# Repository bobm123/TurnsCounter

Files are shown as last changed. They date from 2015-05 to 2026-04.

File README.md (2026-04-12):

# Rubber Band Winder Turns Counter

A turns counter for 3D-printed model airplane rubber band winders. Uses two hall effect sensors to count shaft rotations with direction detection, displayed on a small COG LCD.

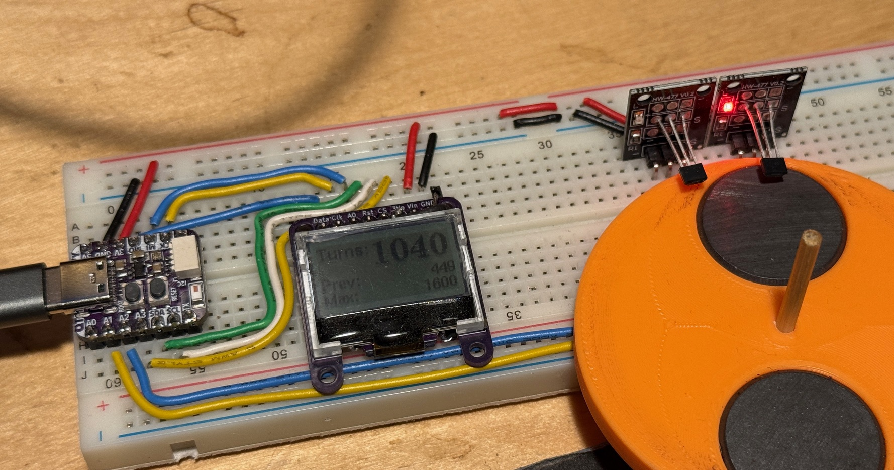
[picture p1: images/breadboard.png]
Breadboard prototype


## Hardware

| Component | Description |
| --- | --- |
| [Adafruit QT Py ESP32-C3](https://www.adafruit.com/product/5405) | Microcontroller board |
| [ERC12864FSF-11](https://www.buydisplay.com/0-96-inch-low-cost-white-128x64-graphic-cog-lcd-display-st7567-spi) | 128x64 COG LCD (ST7567 controller) on [custom breakout board](../../../COGDisplayBreakout/COGDisplayBreakout/) |
| APX805S | Power-on reset IC for display /RST line (on breakout board) |
| 2x KY-003 | Hall effect sensor modules (left and right) |
| Magnet | Mounted on the winder output shaft |

### Pin Mapping

| Function | QT Py Pin | ESP32-C3 GPIO |
| --- | --- | --- |
| Hall sensor - left  | A0 | 4 |
| Hall sensor - right | A1 | 3 |
| Button (BOOT) | BOOT | 9 |
| NeoPixel | - | 2 |
| Display SCK | SCK | 10 |
| Display SDA | MO | 7 |
| Display CS | - | tied low |
| Display DC | MI | 8 |
| Display RST | - | APX805S |
| Backlight LED | A3 | 0 |

## Features

### Turn Counting

Two KY-003 hall effect sensors detect a magnet on the rotating shaft. The left sensor triggers an interrupt; at that moment the right sensor is read to determine direction:

- Left sensor activates first: count increments (winding)
- Right sensor activates first: count decrements (unwinding)

### Display

The 128x64 LCD shows three values:

- **Turns** - current count (large font)
- **Prev** - count saved from last reset
- **Max** - maximum turns set point

### Button (BOOT)

- **Short press** (normal mode): saves current count to "Prev" and resets count to zero
- **Short press** (set-mode): exits set-mode
- **Long press** (3 seconds): enters set-mode, where turning the crank adjusts the max turns value by +/-10 per turn. The max value flashes on the display while in set-mode.

### Warnings

As the absolute turn count approaches the max set point:

- **80%**: NeoPixel flashes yellow
- **90%**: NeoPixel flashes red, backlight flashes

Warnings trigger regardless of winding direction since rubber bands break under strain in either direction.

### Backlight Sleep

The backlight turns off after 1 minute of inactivity (no turns or button presses) and turns back on automatically when activity resumes. The LCD remains readable without the backlight in good lighting.

## Building

### Dependencies

Install these via the Arduino IDE Library Manager:

- [U8g2](https://github.com/olikraus/u8g2) - display graphics
- [Adafruit NeoPixel](https://github.com/adafruit/Adafruit_NeoPixel) - RGB LED control

### Board Setup

1. In Arduino IDE, install the ESP32 board support package
2. Select board: **Adafruit QT Py ESP32-C3**
3. Open `ERC12864_TurnsCounter/ERC12864_TurnsCounter.ino`
4. Compile and upload

### Troubleshooting

- **Direction inverted**: swap `HALL_LEFT` and `HALL_RIGHT` pin definitions
- **Double-counting**: increase `DEBOUNCE_MS` (default 10)
- **Missing counts at speed**: decrease `DEBOUNCE_MS`
- Serial monitor at 115200 baud prints turn counts and button events

## Repository Structure

```
ERC12864_TurnsCounter/   Current sketch (QT Py ESP32-C3 + ERC12864 LCD)
TurnsCounter/            Original reference sketch (ATmega + SSD1306 OLED)
JulianCode/              Reference: low-level SSD1306 OLED control
PinChangeInterrupts/     Reference: AVR pin-change interrupts
U8libExample/            Reference: U8glib display example
SoftServoExample/        Reference: Adafruit Trinket servo control
blinknodelay/            Reference: non-blocking blink pattern
Documents/               Datasheets (QT Py, hall effect sensors, displays)
STLs/                    3D printed parts (magnet disk for shaft)
```

## Future Plans

- LiPo battery support via [Adafruit LiPo Charger BFF](https://www.adafruit.com/product/5397) (A2 is now free for battery voltage sensing)
- Deep sleep mode with NVS save/restore of turn count
- Progress bar on display
- Custom PC board to replace the breadboard wiring
- Battery charge indicator

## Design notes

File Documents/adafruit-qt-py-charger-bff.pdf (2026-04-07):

# Adafruit LiIon or LiPoly Charger BFF Add-On for QT Py

Created by Kattni Rembor

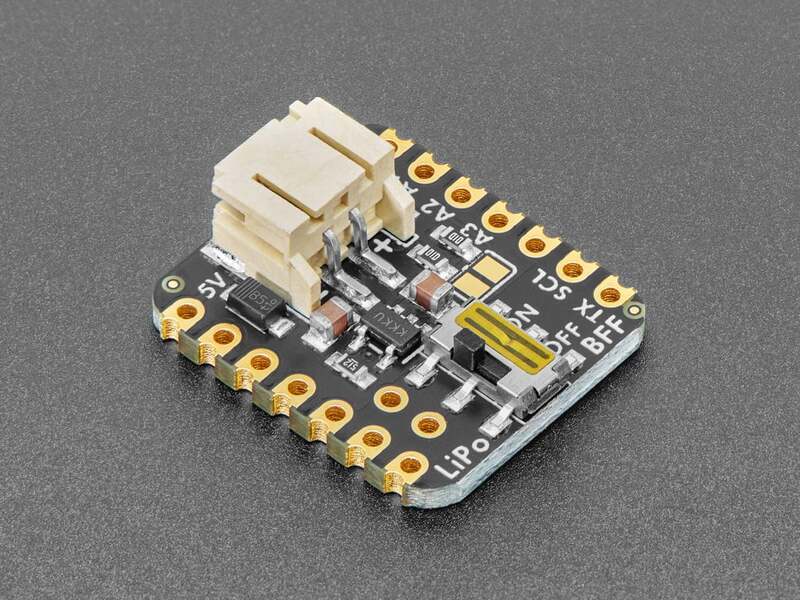
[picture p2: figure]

https://learn.adafruit.com/adafruit-qt-py-charger-bff

Last updated on 2025-12-19 03:03:49 PM UTC

©Adafruit Industries | Page 1 of 14

3
7

11

## Table of Contents

Overview
Pinouts
- Power Slide Switch
- Power Switch Breakout Pads
- Battery JST Connector
- Charge LED
- Battery Monitor Pin and Jumper
- Charge Chip and Voltage Divider
Downloads
- Files
- Schematic and Fab Print
- 3D Model

# Overview

Is your QT Py all alone (https://www.adafruit.com/?q=qt+py&sort=BestMatch) (https://adafru.it/18eZ), lacking a friend to travel the wide world with? When you were a kid you may have learned about the "buddy" system. Well, this product is kinda like that! A board that will watch your QT Py's back and give it the power and support to wander out past your USB port.

Revision History:
As of December 12, 2025 - We added two breakout pads for the on/off switch for an external switch if desired. We also updated the PCB with Adafruit Pinguin to make a lovely and legible silkscreen.

•

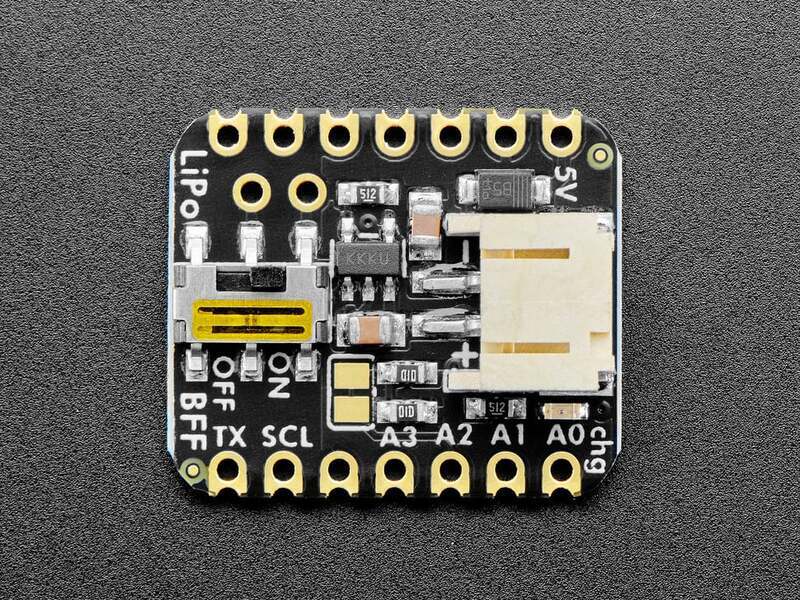
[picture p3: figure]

This little lipo charger is designed to fit onto the back of any QT Py board, and make it easy for portable powering. Simply plug any standard 3.7V/4.2V lithium polymer or lithium-ion rechargeable battery into the JST plug on the end. When powered by the USB port on the QT Py, the charger kicks in and will charge up the battery at 200mA max rate. You'll see the yellow LED light up when that happens.
When the USB is removed, the battery will reverse charge into the 5V port via a Schottky diode. You can turn it on or off with the built in slide switch as well.

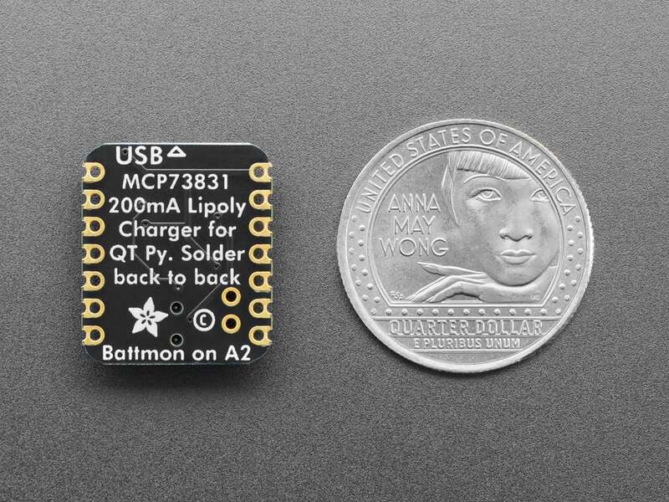
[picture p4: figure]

A simple voltage divider on the cathode side of the diode and connected to pin A2 will let your firmware detect basic modes: if the voltage is over 4.3V, it is probably plugged into USB. If the voltage is 4.2V or below its probably running on the Lipoly battery and you can roughly determine the battery state.

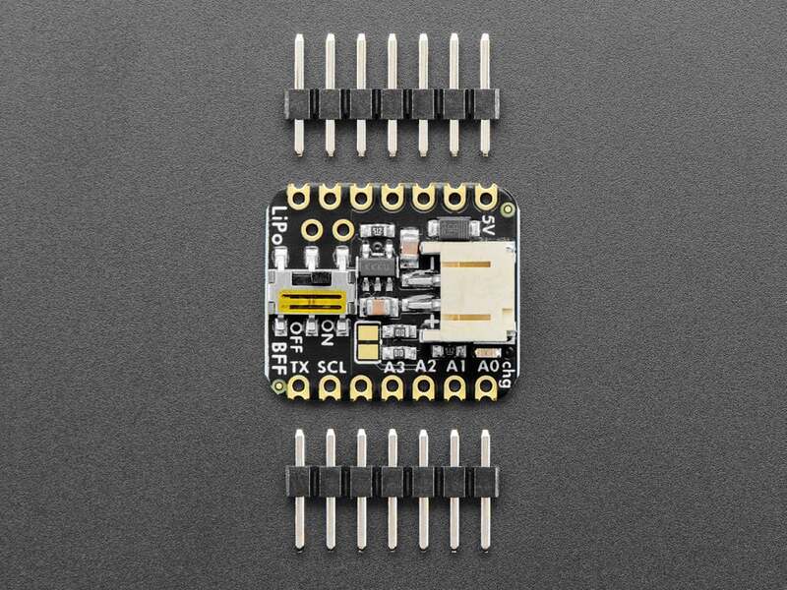
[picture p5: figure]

We include some header that you can solder to your QT Py. You can also pick up an Itsy Bitsy short female header kit to make it removable but compact (https://www.adafruit.com/product/4174) (http://adafru.it/4174), you'll just need to trim down the headers to 7 pins long.
For use with Adafruit LiPoly/LiIon batteries only! Other batteries may have different voltage, chemistry, polarity, or pinout.

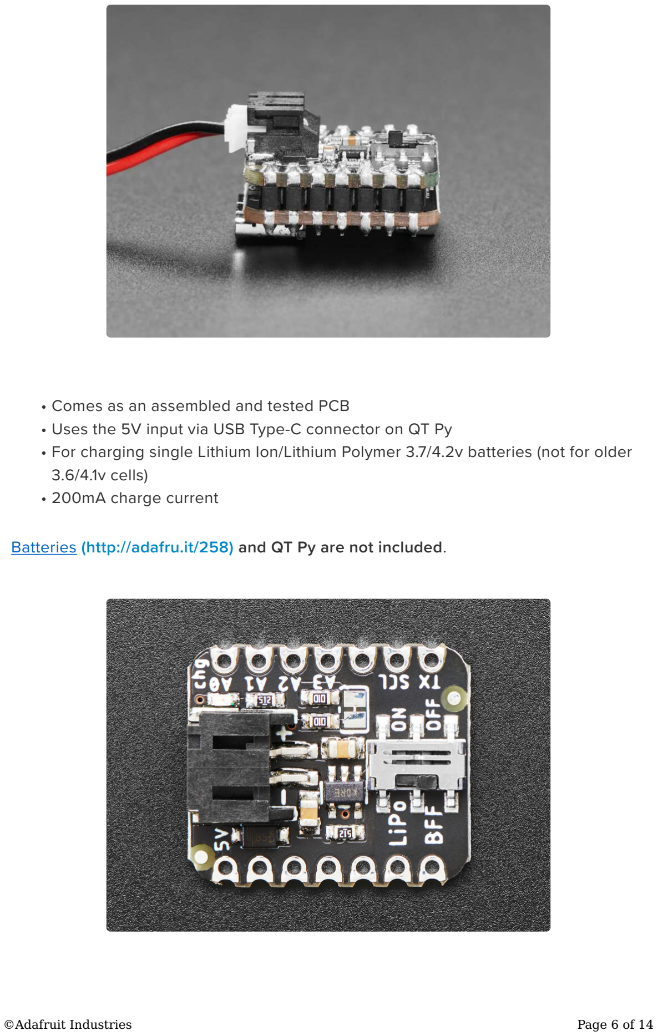
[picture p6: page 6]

Comes as an assembled and tested PCB
Uses the 5V input via USB Type-C connector on QT Py
For charging single Lithium Ion/Lithium Polymer 3.7/4.2v batteries (not for older 3.6/4.1v cells)
200mA charge current

Batteries (http://www.adafruit.com/products/258) (http://adafru.it/258) and QT Py are not included.

•
•
•

•

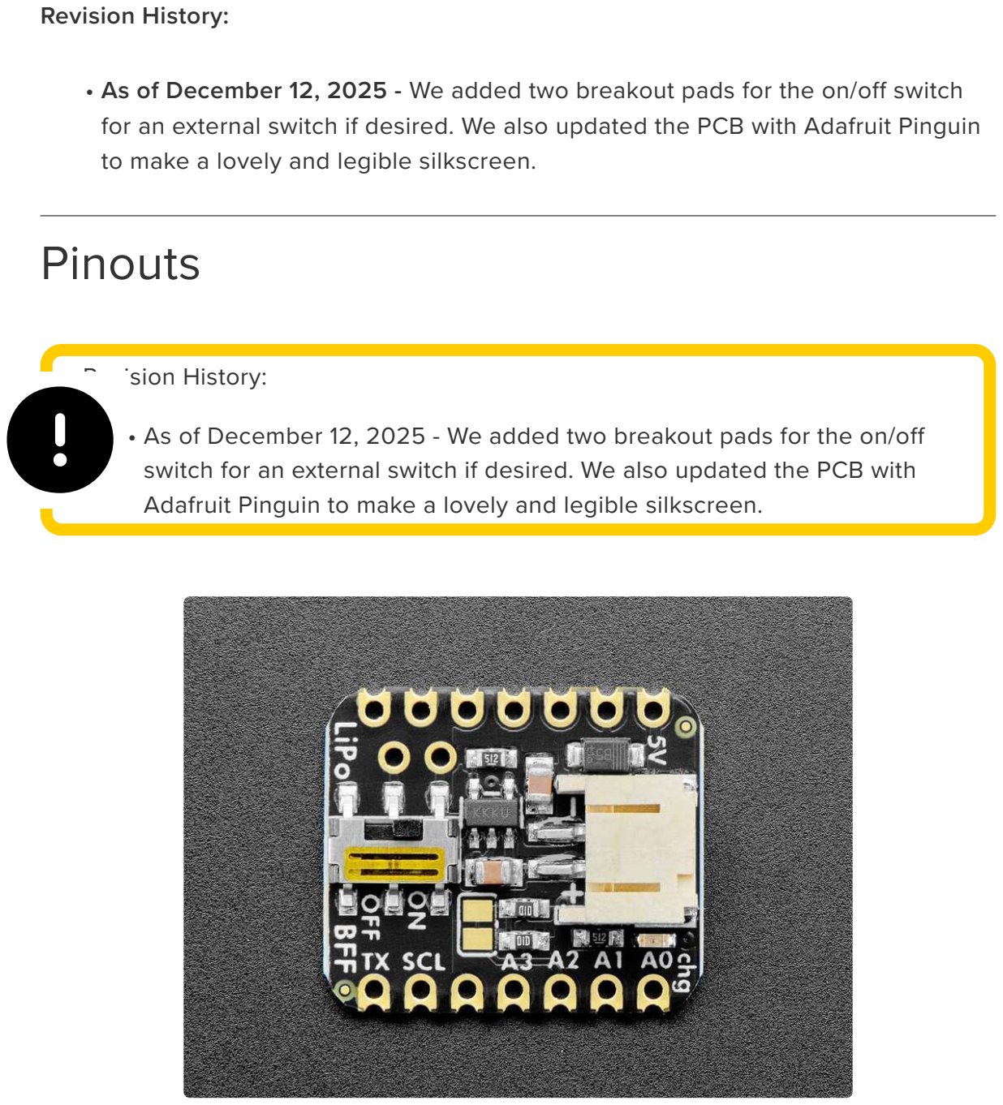
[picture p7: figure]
Revision History:; Pinouts

As of December 12, 2025 - We added two breakout pads for the on/off switch for an external switch if desired. We also updated the PCB with Adafruit Pinguin to make a lovely and legible silkscreen.

As of December 12, 2025 - We added two breakout pads for the on/off switch for an external switch if desired. We also updated the PCB with Adafruit Pinguin to make a lovely and legible silkscreen.

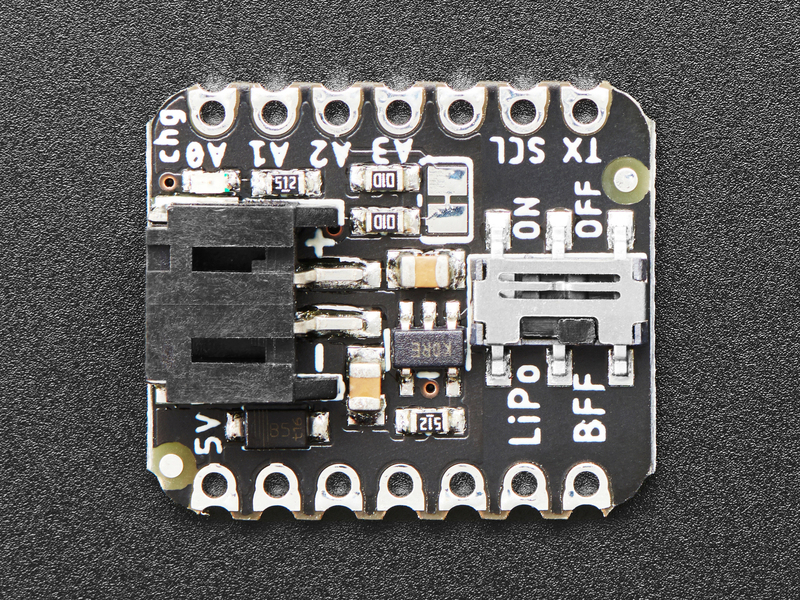
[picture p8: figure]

This QT Py BFF has a bunch of features packed into a cute little board. This page will explain the hardware!

## Power Slide Switch

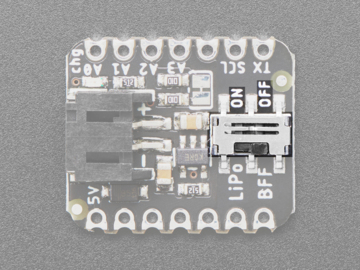
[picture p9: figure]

The power slide switch, located in the middle of the right side of the board, turns the BFF on or off, but only when the QT Py is NOT plugged into USB power.

## Power Switch Breakout Pads

On rev C of the BFF are power switch breakout pads. They are located next to the power slide switch and let you wire up an external switch to use instead of the slide switch.

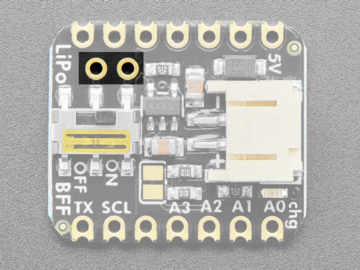
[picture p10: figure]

## Battery JST Connector

The battery JST connector, located in the middle of the left side of the board, enables you to plug in any standard 3.7V/ 4.2V lithium polymer or lithium-ion rechargeable battery to the BFF.
For use with Adafruit LiPoly/LiIon batteries only! Other batteries may have different voltage, chemistry, polarity, or pinout.

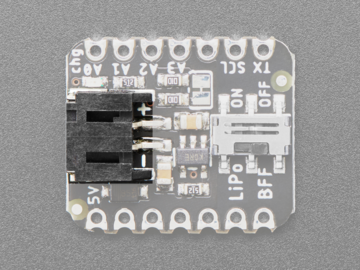
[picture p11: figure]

## Charge LED

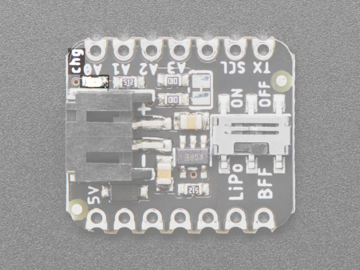
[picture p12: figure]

The charge LED, located in the upper left corner of the board, lights up when the battery is charging. Charging occurs only when the QT Py is plugged into USB power.

## Battery Monitor Pin and Jumper

Pin A2, located to the left of center along the top edge of the board, is connected to the simple voltage divider, which will let your firmware detect basic modes.
It measure the 5V line which is after a schottkey diode.
If the voltage is over 2.0V (4V divided by two due to the divider), it is probably plugged into USB. If the voltage is 1.95V or below, it's probably running on the Lipoly battery and you can roughly determine the battery state.
Just be sure to double the reading to get the voltage reading, as the measurement divider reduces the voltage by 1/2.

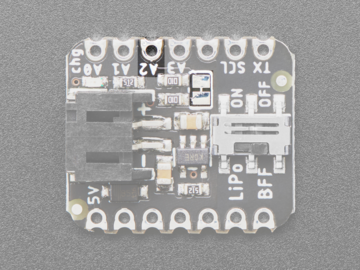
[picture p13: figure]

There are a pair of jumper pads, located to the right of center, below the pins along the top edge. These pads are connected to pin A2, between the pin and the voltage divider. In the event that you want to use pin A2 for something other than battery monitoring, you can cut the trace between these pads to disable monitoring on pin A2. Solder the pads back together to enable monitoring again.

## Charge Chip and Voltage Divider

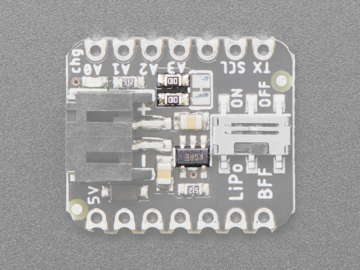
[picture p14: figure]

The MCP73831 lipo charge chip, located near the center of the board, will charge up the battery at 200mA max rate. Charging occurs only while the QT Py is plugged into USB, and will happen regardless of the status of the slide switch. When the chip is charging a battery, the charge LED will light up.

The voltage divider, located below the A3 pin label on the BFF silk, is connected between A2 and 5V via the cathode side of a diode. It allows for simple monitoring of voltage levels, which can indicate whether the QT Py is running off USB, or being powered by a battery plugged into the BFF.
To obtain the voltage level from A2 using CircuitPython, run the following code.

import time
import board
import analogio

analog_pin = analogio.AnalogIn(board.A2)

def get_voltage(pin):
return (pin.value / 65535) * 3.3 * 2.0 // voltage divider reduces // voltage by 1/2 do must
// double to get the voltage while True:
print(get_voltage(analog_pin)) time.sleep(0.1)

# Downloads

## Files

MCP73831 Datasheet (https://cdn-learn.adafruit.com/assets/assets/000/110/654/original/MCP73831-Family-Data-Sheet-DS20001984H.pdf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) (https://adafru.it/Zzd)
EagleCAD PCB files on GitHub (https://github.com/adafruit/Adafruit-Charger-BFF-PCB) (https://adafru.it/Zze)
Fritzing object in the Adafruit Fritzing Library - rev B (https://github.com/adafruit/Fritzing-Library/blob/master/parts/Adafruit%20LiPoly%20Charger%20BFF%20for%20QT%20Py_rev%20A.fzpz) (https://adafru.it/1ayc) Fritzing object in the Adafruit Fritzing Library - rev C (https://github.com/adafruit/Fritzing-Library/blob/master/parts/Adafruit%20LiPoly%20Charger%20BFF%20for%20QT%20Py_rev%20C.fzpz) (https://adafru.it/1ayd) 3D models on GitHub (https://github.com/adafruit/Adafruit_CAD_Parts/tree/main/5397%20Lipo%20Charger%20BFF) (https://adafru.it/18f0)

•
•
•
•
•

## Schematic and Fab Print

Rev C

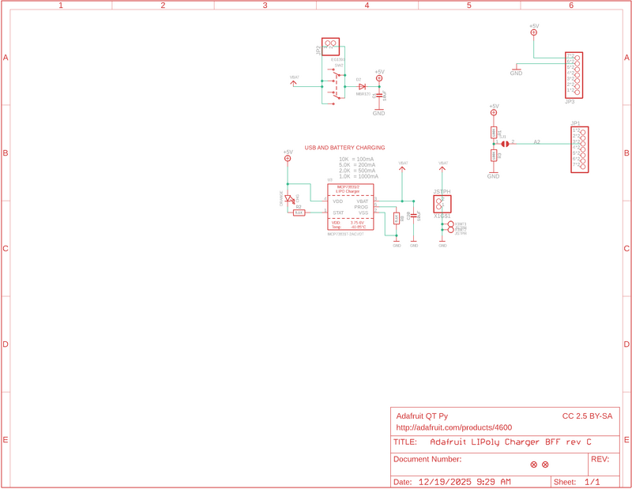
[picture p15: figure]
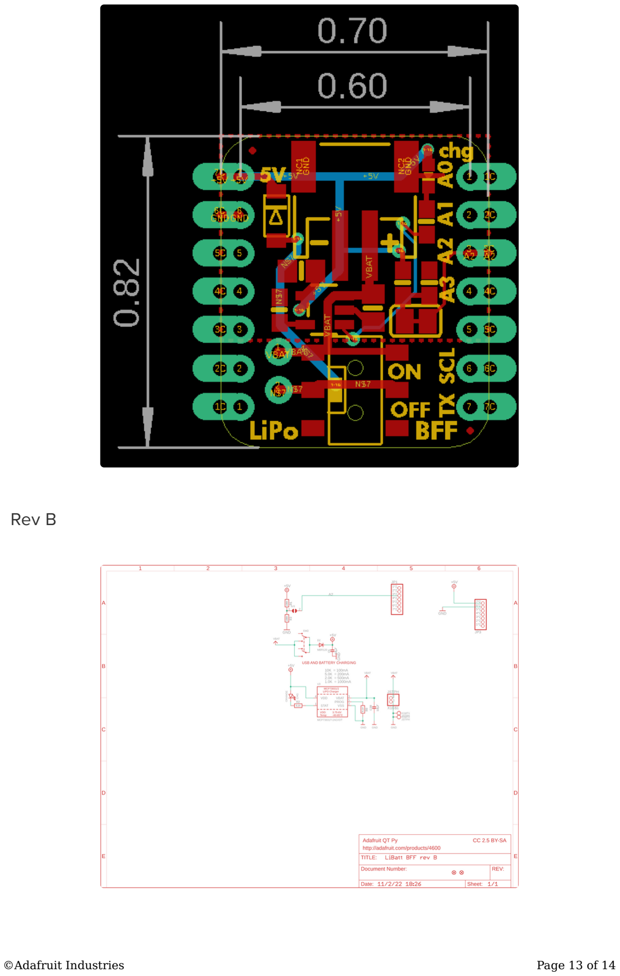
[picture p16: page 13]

Rev B

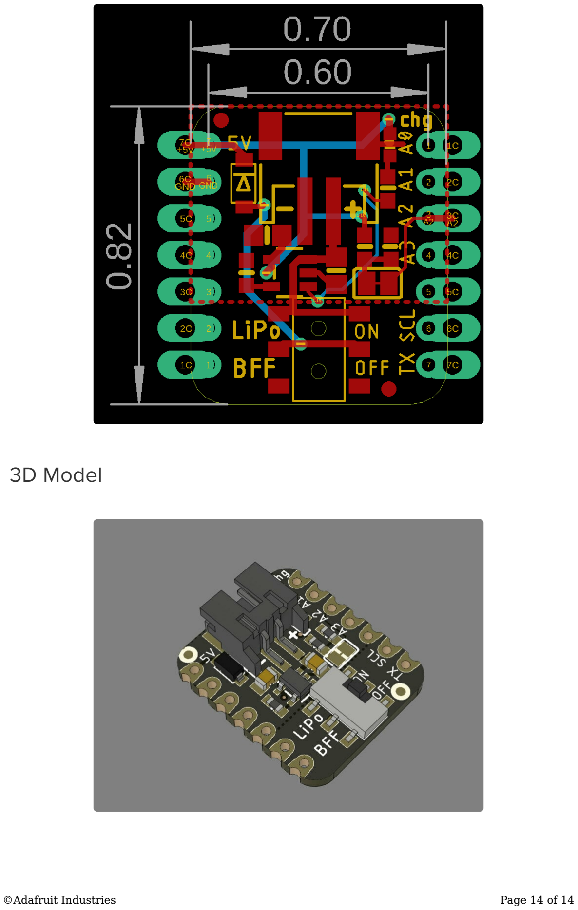
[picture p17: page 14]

## 3D Model

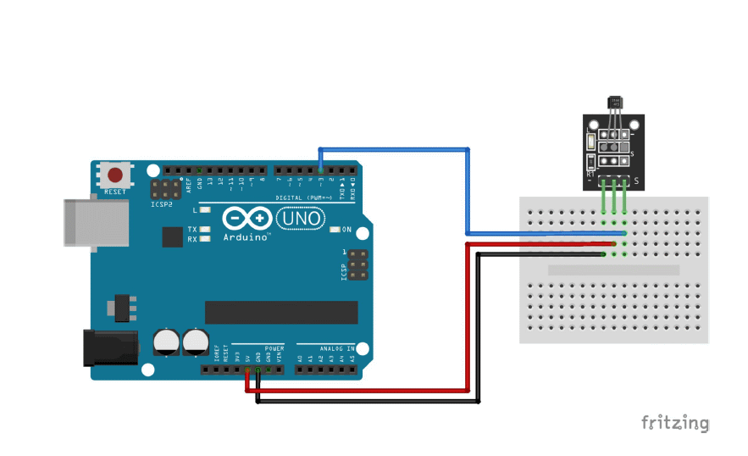
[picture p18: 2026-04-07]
Documents/Uno+HallEffectModule.gif

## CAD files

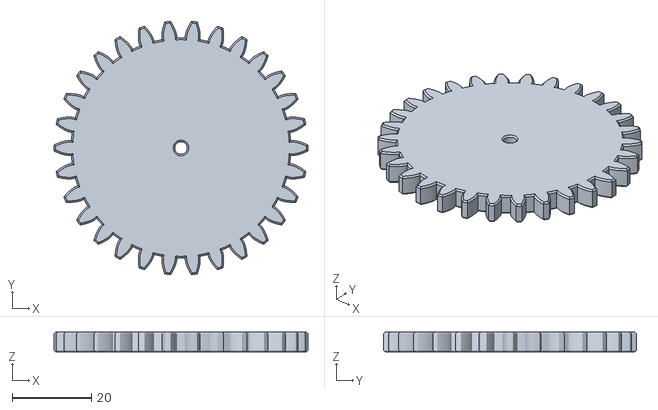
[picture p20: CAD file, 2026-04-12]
STLs/Spur Gear (30 teeth).stl
64.0 x 63.8 x 5.00

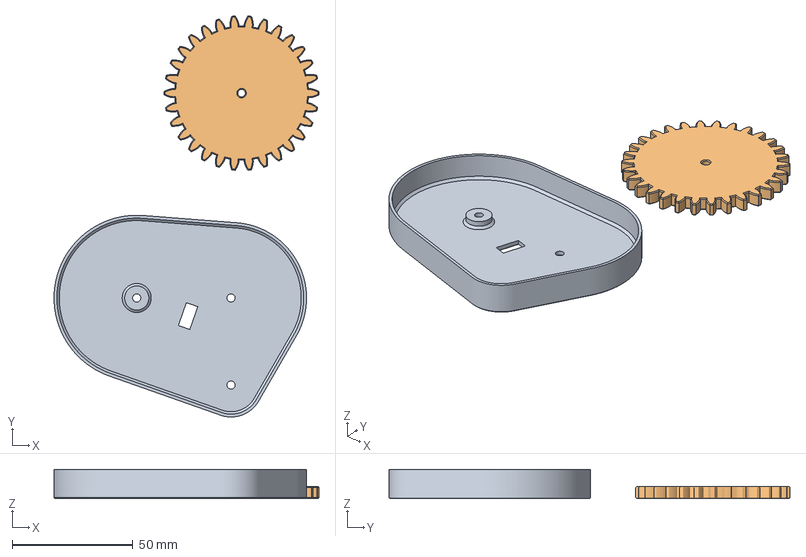
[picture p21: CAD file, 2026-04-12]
STLs/ElectronicsBay.3mf
109.5 x 165.8 x 12.0 mm
ElectronicsBay.stl
Spur Gear (30 teeth).stl

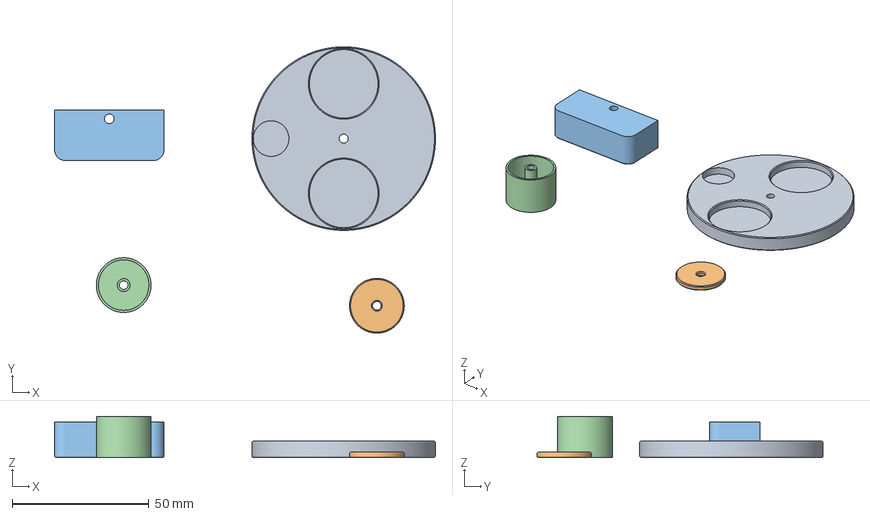
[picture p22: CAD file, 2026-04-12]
STLs/MagnetDisk.3mf
139.1 x 104.5 x 15.0 mm
MagnetDisk.stl
Washer.stl
MagnetDisk-bearing.stl
SeamTest.stl

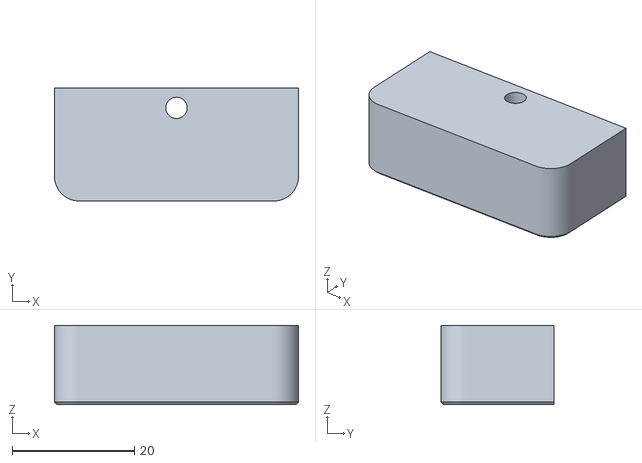
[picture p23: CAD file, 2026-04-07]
STLs/MagnetDisk-bearing.stl
40.0 x 18.5 x 13.0

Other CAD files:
STLs/MagnetDisk.stl

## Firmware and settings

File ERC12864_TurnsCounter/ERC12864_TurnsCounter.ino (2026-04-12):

#include <U8g2lib.h>
#include <SPI.h>
#include <Adafruit_NeoPixel.h>

// QT Py ESP32-C3 display pin mappings
// CS tied low on breakout (single SPI device). RST managed by APX805S on breakout board.
U8G2_ST7565_ERC12864_ALT_F_4W_SW_SPI u8g2(U8G2_R0, /* clock=*/ 10, /* data=*/ 7, /* cs=*/ U8X8_PIN_NONE, /* dc=*/ 8, /* reset=*/ U8X8_PIN_NONE);
#define BACKLIGHT_LED 0

// Hall effect sensor pins (KY-003 modules)
// Left sensor triggers the interrupt; right sensor is read for direction
#define HALL_LEFT   4   // A0 = GPIO4 - interrupt pin
#define HALL_RIGHT  3   // A1 = GPIO3 - direction pin

// Button pin (BOOT button on QT Py ESP32-C3)
#define BUTTON_PIN  9   // GPIO9 - active LOW with internal pull-up

// NeoPixel
#define NEOPIXEL_PIN 2
Adafruit_NeoPixel pixel(1, NEOPIXEL_PIN, NEO_GRB + NEO_KHZ800);

// Warning thresholds (percentage of maxTurns)
#define WARN_THRESHOLD  80
#define ALERT_THRESHOLD 90

// Debounce time in milliseconds
#define DEBOUNCE_MS 10

// Inactivity timeout for backlight (milliseconds)
#define INACTIVE_TIMEOUT 60000

// Long press threshold to enter set-mode (milliseconds)
#define SETMODE_TIME 3000

// Default max turns
#define DEFAULT_MAX 1600

// Volatile state shared between ISR and main loop
volatile int gEncoderPos = 0;
volatile unsigned long gLastInterruptTime = 0;
volatile unsigned long gLastActivityTime = 0;

// ISR: called on FALLING edge of left hall sensor (magnet detected)
void IRAM_ATTR hallSensorISR() {
  unsigned long now = millis();
  if (now - gLastInterruptTime < DEBOUNCE_MS) {
    return;
  }
  gLastInterruptTime = now;

  gLastActivityTime = now;

  // Same state = winding (left closed first), different = unwinding
  if (digitalRead(HALL_LEFT) == digitalRead(HALL_RIGHT)) {
    gEncoderPos++;
  } else {
    gEncoderPos--;
  }
}

void setup() {
  Serial.begin(115200);
  Serial.println("Turns Counter - Hall Effect");

  // Backlight on
  pinMode(BACKLIGHT_LED, OUTPUT);
  digitalWrite(BACKLIGHT_LED, HIGH);

  // NeoPixel power enable and init
#ifdef NEOPIXEL_POWER
  pinMode(NEOPIXEL_POWER, OUTPUT);
  digitalWrite(NEOPIXEL_POWER, HIGH);
#endif
  pixel.begin();
  pixel.setBrightness(50);
  pixel.clear();
  pixel.show();

  // Hall effect sensor inputs
  pinMode(HALL_LEFT, INPUT_PULLUP);
  pinMode(HALL_RIGHT, INPUT_PULLUP);

  // Button input (active LOW, has internal pull-up on the board)
  pinMode(BUTTON_PIN, INPUT_PULLUP);

  // Interrupt on left sensor: FALLING = magnet detected (KY-003 goes LOW)
  attachInterrupt(HALL_LEFT, hallSensorISR, FALLING);

  // Initialize display
  u8g2.begin();
}

int turnsCount = 0;
int prevTurns = 0;       // saved count from last reset
int maxTurns = DEFAULT_MAX;
int prevEncoderPos = 0;
int prevDisplayedCount = -99999;
bool setMode = false;
bool buttonWasUp = true;
unsigned long buttonDownTime = 0;
bool longPressHandled = false;
char buffer[12];

void loop() {
  unsigned long now = millis();

  // --- Encoder delta ---
  int encoderPos = gEncoderPos;
  int delta = encoderPos - prevEncoderPos;
  if (delta != 0) {
    prevEncoderPos = encoderPos;
    if (setMode) {
      maxTurns += 10 * delta;
      if (maxTurns < 0) maxTurns = 0;
    } else {
      turnsCount += delta;
    }
  }

  // --- Button state machine ---
  bool buttonDown = (digitalRead(BUTTON_PIN) == LOW);

  if (buttonDown && buttonWasUp) {
    // Button just pressed
    buttonDownTime = now;
    longPressHandled = false;
    gLastActivityTime = now;
  }

  if (buttonDown && !buttonWasUp) {
    // Button held - check for long press
    if (!longPressHandled && (now - buttonDownTime > SETMODE_TIME)) {
      longPressHandled = true;
      if (!setMode) {
        setMode = true;
        Serial.println("Set mode ON");
      }
    }
  }

  if (!buttonDown && !buttonWasUp) {
    // Button just released
    if (!longPressHandled) {
      // Short press
      if (setMode) {
        setMode = false;
        Serial.print("Set mode OFF, max=");
        Serial.println(maxTurns);
      } else {
        prevTurns = turnsCount;
        turnsCount = 0;
        gEncoderPos = 0;
        prevEncoderPos = 0;
        Serial.print("Reset. Prev=");
        Serial.println(prevTurns);
      }
    }
    gLastActivityTime = now;
  }

  buttonWasUp = !buttonDown;

  // --- Serial debug on count change ---
  if (turnsCount != prevDisplayedCount) {
    prevDisplayedCount = turnsCount;
    Serial.print("Turns: ");
    Serial.println(turnsCount);
  }

  // --- Warning indicators and backlight ---
  int pctMax = (maxTurns > 0) ? (100L * abs(turnsCount) / maxTurns) : 0;
  bool active = (now - gLastActivityTime) < INACTIVE_TIMEOUT;

  if (!active) {
    // Inactive - backlight off, NeoPixel off
    digitalWrite(BACKLIGHT_LED, LOW);
    pixel.clear();
  } else if (pctMax >= ALERT_THRESHOLD) {
    // Over 90%: fast flash red NeoPixel + backlight
    bool flash = (now / 100) % 2;  // ~5 Hz
    pixel.setPixelColor(0, flash ? pixel.Color(255, 0, 0) : 0);
    digitalWrite(BACKLIGHT_LED, flash ? HIGH : LOW);
  } else if (pctMax >= WARN_THRESHOLD) {
    // Over 80%: slow flash yellow NeoPixel, backlight steady
    bool flash = (now / 300) % 2;  // ~1.7 Hz
    pixel.setPixelColor(0, flash ? pixel.Color(255, 150, 0) : 0);
    digitalWrite(BACKLIGHT_LED, HIGH);
  } else {
    // Normal - backlight on, NeoPixel off
    digitalWrite(BACKLIGHT_LED, HIGH);
    pixel.clear();
  }
  pixel.show();

  // --- Update display ---
  // Flash effect for set-mode: hide max value briefly
  bool flashOn = setMode && ((now / 300) % 2 == 0);

  u8g2.firstPage();
  do {
    // Row 1: Current count (large)
    u8g2.setFont(u8g2_font_helvB12_tr);
    u8g2.drawStr(0, 15, "Turns:");
    itoa(turnsCount, buffer, 10);
    u8g2.setFont(u8g2_font_ncenB24_tr);
    int swidth = u8g2.getStrWidth(buffer);
    u8g2.drawStr(128 - swidth, 27, buffer);

    // Row 2: Previous count
    u8g2.setFont(u8g2_font_helvB10_tr);
    u8g2.drawStr(0, 46, "Prev:");
    itoa(prevTurns, buffer, 10);
    swidth = u8g2.getStrWidth(buffer);
    u8g2.drawStr(128 - swidth, 46, buffer);

    // Row 3: Max turns (flashes in set-mode)
    u8g2.drawStr(0, 61, "Max:");
    if (!flashOn) {
      itoa(maxTurns, buffer, 10);
      swidth = u8g2.getStrWidth(buffer);
      u8g2.drawStr(128 - swidth, 61, buffer);
    }
  } while (u8g2.nextPage());

  delay(50);
}

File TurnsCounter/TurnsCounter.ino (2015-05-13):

/*********************************************************************
Turns counter for 3D printed Rubber Motor Winder

Uses two hall effect devices to count turns on the output shaft in 
either direction and display total count on an OLED display. A reset 
button zeros the count. Future: hold button while turning the crank
to set turns limit. Display shows a progress bar and flashes a warning 
at 80% and 90% of set point. On/Off switch and sleep mode to preserve
LiPo batter. Rechargeable from a USB cable

*********************************************************************/

#include "U8glib.h"
#include <avr/eeprom.h>

#define LEDPIN        13   // onboard LED
#define BUTTON_PIN    A0   // Port 2 interrupt 0
#define ENCODER_PINB  A1   // Port 2 Interrupt 1
#define ENCODER_PINA  A2   // Port 2 interrupt 2
#define OLED_RESET    A3

U8GLIB_SSD1306_128X32 u8g(U8G_I2C_OPT_NONE);	// I2C / TWI 

#define INACTIVE_LIMIT  30000
#define SETMODETIME     3000
#define DEFAULTMAX      1600

volatile unsigned int gEncoderPos = 0;
volatile int gButtonState;
volatile long gInactiveMillis;
volatile long gButtonDownMillis;
volatile int gPrevButtonPin;  
volatile int gPrevEncoderPinA;

volatile int toggleLed = 0;


void setup()
{
  pinMode(LEDPIN, OUTPUT);
  pinMode(BUTTON_PIN, INPUT_PULLUP);
  pinMode(ENCODER_PINA, INPUT_PULLUP); 
  pinMode(ENCODER_PINB, INPUT_PULLUP); 
  gPrevButtonPin = digitalRead(BUTTON_PIN);
  gPrevEncoderPinA = digitalRead(ENCODER_PINA);
  
  InitializeInterrupt();
  
  //Serial.begin(115200);
  //Serial.println("TurnsCounter");
}


void loop() {
  int turnsCount = 0;
  int maxTurns = DEFAULTMAX; // TODO: save last value in  NVRAM
  int inc = 1;
  int prevButtonState = 0;
  int prevEncoderPos = 0;
  bool setMode = false;

  gInactiveMillis = 0;
  
  gButtonState = digitalRead(BUTTON_PIN);
  prevButtonState = gButtonState;
  gButtonDownMillis = 0;

  //Serial.print("Button State ");
  //Serial.println(gButtonState);
  
  // Print any new count values and toggle the output LED
  while (true) {

    // State Machine with two states (setMode=[true,false])
    if (gButtonState == LOW) {
      if (millis() - gButtonDownMillis > SETMODETIME) {
        if (setMode == false) {
          setMode = true;
          //maxTurns = DEFAULTMAX;
          //gRefreshDisplay = true;
          //Serial.println("goto set mode");
        }
      }
    }
    
    if (prevButtonState == HIGH && gButtonState == LOW) {
      turnsCount = 0;
      //gRefreshDisplay = true;
      //Serial.println("State change Low to High");
      if (setMode == true) {
        setMode = false;
        //Serial.println("leave set mode");
      }
    }
    prevButtonState = gButtonState;

    // Something changeD, so update values and displap
    if (prevEncoderPos != gEncoderPos) {
      //gRefreshDisplay = true;
      if (setMode) {
        maxTurns += 10 *(gEncoderPos - prevEncoderPos);
      }
      else {
        turnsCount += gEncoderPos - prevEncoderPos;
      }
      prevEncoderPos = gEncoderPos;
    }
    
    // LED indicates setMode
    //digitalWrite(LEDPIN, setMode);

    // LED indicates setMode
    digitalWrite(LEDPIN, toggleLed);

    // u8glib picture loop
    u8g.firstPage();
    do {
      if (millis() - gInactiveMillis < INACTIVE_LIMIT) {
        UpdateCountDisplay_u8g(turnsCount, maxTurns, setMode);
      }
      else {
        // Turn off the display if nothing happends for a while
        u8g.setFont(u8g_font_helvR12);  
        u8g.setPrintPos(48, 24);
        u8g.print("Sleep");
      }
    } while (u8g.nextPage());
    delay(50);     // rebuild the picture after some delay
    // u8glib picture loop
  } //end while(true)
} // end loop()


void InitializeInterrupt(){
  cli();		// switch interrupts off while messing with their settings  
  PCICR =0x02;          // Enable PCINT1 interrupt
  PCMSK1 = 0b00000111;  // Mask lower all but bits 0, 1, & 2
  sei();		// turn interrupts back on
}


ISR(PCINT1_vect) {
  
  if (toggleLed == 0) {
    toggleLed = 1;
  }
  else {
    toggleLed = 0;
  }    
  
  gInactiveMillis = millis();
  
  //Emulate AttachInterrupt (..., CHANGE)
  int bp = digitalRead(BUTTON_PIN);
  if (bp != gPrevButtonPin) {
    doButton(bp);
  }

  //Emulate AttachInterrupt (..., RISING)
  if (digitalRead(ENCODER_PINA)==0 && gPrevEncoderPinA == 1) {
    doEncoder();
  }
  gPrevButtonPin = digitalRead(BUTTON_PIN);
  gPrevEncoderPinA = digitalRead(ENCODER_PINA);
}


void doButton(int pinState) {
  //gRefreshDisplay = true;
  gButtonState = pinState;
  if (gButtonState == LOW) {
    gButtonDownMillis = millis();
    //Serial.println("Button Down");
  }
//  else {
//    Serial.println("Button Up");
//  }
}


void doEncoder() {
  /* If pinA and pinB are both high or both low, it is spinning
   * forward. If they're different, it's going backward.
   */
  if (digitalRead(ENCODER_PINA) == digitalRead(ENCODER_PINB)) {
    gEncoderPos += 1;
  } else {
    gEncoderPos += -1;
  }
}


int flash_count = 0;
#define FLASH_CYCLE     19
#define FLASH_ON_COUNT  15
void UpdateCountDisplay_u8g(int turns, int max_turns, bool display_mode)
{
  flash_count += 1;
  if (flash_count > FLASH_CYCLE) {
    flash_count = 0;
  }
  
  // show the new value    
  if (display_mode)  {
    u8g.setFont(u8g_font_helvR12);  
    u8g.setPrintPos(0, 12);
    u8g.print("Set Max Turns");
    u8g.setPrintPos(88, 30);
    u8g.print(max_turns);
  }
  else {
    long pct_max = 100L * abs(turns) / max_turns;
    char st_turns[10];
    itoa(turns, st_turns, 10);
    u8g.setFont(u8g_font_helvR24);  
    u8g.drawStr(85 - u8g.getStrWidth(st_turns), 30, st_turns);

    u8g.setFont(u8g_font_helvR12);  
    u8g.setPrintPos(88, 30);
    u8g.print(max_turns);
    
    if (pct_max < 80 || flash_count < FLASH_ON_COUNT) {
      u8g.setPrintPos(88, 12);
      u8g.print(pct_max);
      u8g.print(" %");
    }
  }
}

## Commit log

2015-03-21 Moves the counter siaply update into its own function. ANd reorganizes the encoder input simmulation
2015-03-21 First working count display with encoder inputs from ISR
2015-03-22 Adds a simpel reset switch input to clear the count display
2015-03-22 Rearagged onput digital inputs so button is on int1
2015-03-26 fixes spellings and typoes in banner
    [TurnsCounter.ino]
2015-03-26 First working example of button hold logic. Press button leaves setMode, press and hold enters it again
2015-03-26 removes more commented display sample code
2015-03-27 set mode adds tunrs x10, reorganized main while(1) loop and furthur decouple omf encoderPos variable from turnsCount andmaxCount
2015-03-27 Moves LED outside of position change detect so it accurately reflects set mode state
2015-03-27 Changes some sample files from .txt to .ino
2015-03-27 Found some code examples for display drivers, U8Lib and Julian's homebrew library
2015-03-30 Adds pin change interrupt example
2015-03-30 Changes the pin programming to use the newer Arduino INPUT_PULLUP argument for the pinMode() function. ALso moved the input switch to A3 for more convienient pin outs on the Trinket
2015-03-30 mostly workign interrupts on A1, A2, A3 for Encoder and Button. Button seems to need debounce. TODO: All global variable names should start with 'g'.
2015-03-31 Fixes logic for leave set mode
    [TurnsCounter.ino]
2015-03-31 Adds more infor to the main count display: max turns setting and current precent.
2015-04-04 Adds a sleep mode. Todo: test current draw to see it it actually make any difference.
2015-05-13 Rearranges input pins for better board layout
2026-04-07 Origial work on TurnsCounter, plus some new sample code and docs
    [MagnetDisk-bearing.stl, MagnetDisk.3mf, MagnetDisk.stl]
2026-04-07 Basic Up/Down/Reset function with timout on backlight
    [ERC12864_TurnsCounter.ino]
2026-04-07 Flash the LEDs to warn when approaching max turns
2026-04-09 Moves pins to reserve A2 for the lipo charger
2026-04-12 Removed /RST as /CS connections from QTPy, Adds some 3D models for testing
    [ElectronicsBay.3mf, ElectronicsBay.stl, MagnetDisk.3mf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]
2026-04-18 git ignore
    [ElectronicsBay.stl]
